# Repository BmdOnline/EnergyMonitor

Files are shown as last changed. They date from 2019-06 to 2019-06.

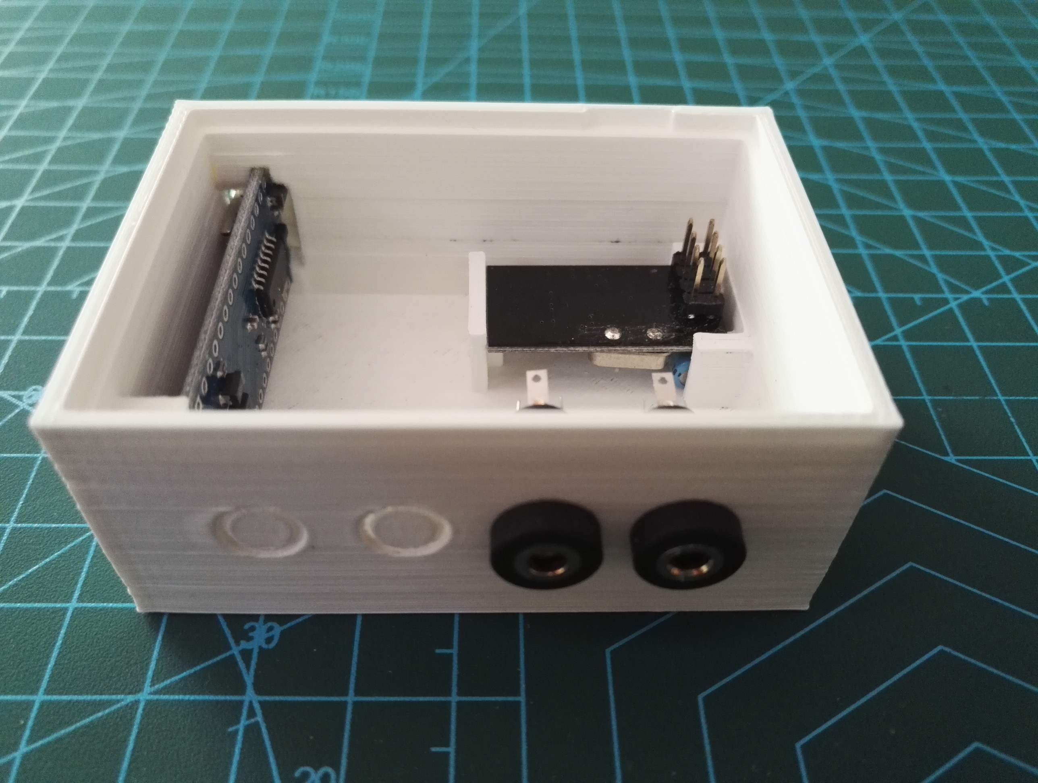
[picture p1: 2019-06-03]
hardware/pictures/IMG_20190603_105925_resize.jpg

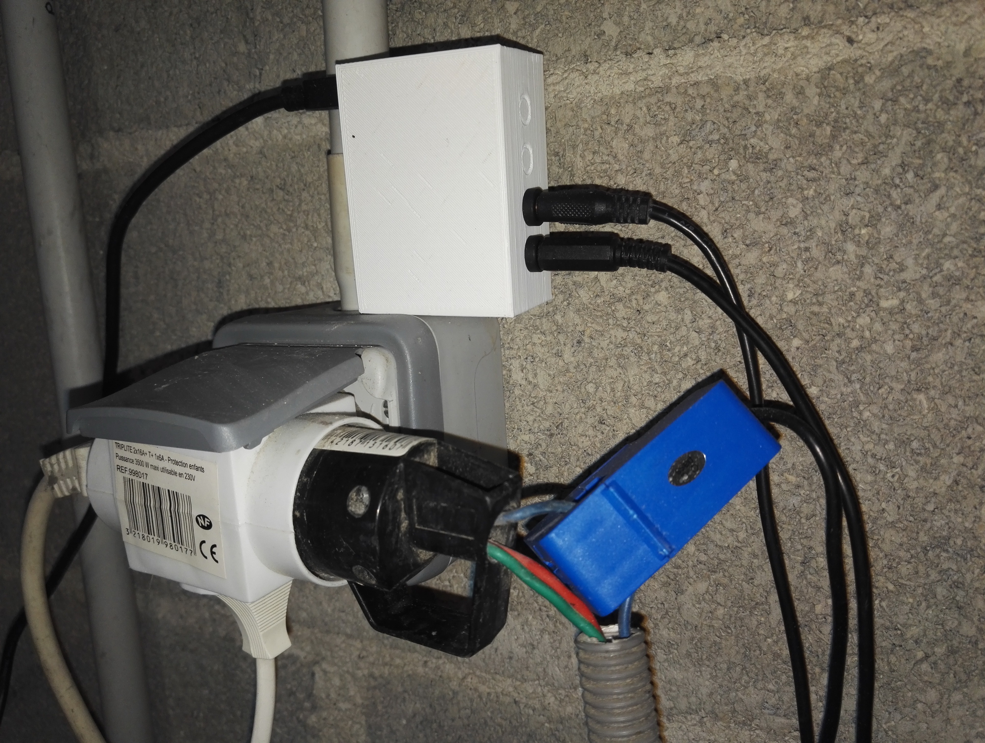
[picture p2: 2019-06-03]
hardware/pictures/IMG_20190603_145601_resize.jpg

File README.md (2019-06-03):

# EnergyMonitor
Arduino energy monitor, using SCT-013-030 current sensors

Project Links :
* [Software part, on GitHub](https://github.com/BmdOnline/EnergyMonitor)
* [Hardware part, on Thingiverse](https://www.thingiverse.com/thing:3670139)

This is a full energy monitor project :
* You can manage 1 to 6 sensors.
* You can configure it through USB (see below).
* It can communicate through USB, with any homemade software.
* It can communicate with any Home Automation System supporting MySensors (I'm using Domoticz).
* Full source is provided, you can customize it.

Needed parts :
* For each sensor :
  * 1x SCT-013-030 current sensor ([AliExpress](https://www.aliexpress.com/wholesale?SearchText=SCT+013+030)).
      * It also works with SCT-013-000 ([AliExpress](https://www.aliexpress.com/wholesale?SearchText=SCT+013+000)) (see below).
  * 1x 3.5mm Audio jack socket ([AliExpress](https://www.aliexpress.com/wholesale?SearchText=3.5mm+Audio+jack+socket)).
  * 2x 100k Resistor ([AliExpress](https://www.aliexpress.com/wholesale?SearchText=100k+Resistor)).
  * 1x 10µF Capacitor ([AliExpress](https://www.aliexpress.com/wholesale?SearchText=10uF+Capacitor)).
* 1x NRF24L01 wireless module ([AliExpress](https://www.aliexpress.com/wholesale?SearchText=NRF24L01)).
  * 1x 10µF Capacitor ([AliExpress](https://www.aliexpress.com/wholesale?SearchText=10uF+Capacitor)) (see below).
* 1x Arduino Nano ([AliExpress](https://www.aliexpress.com/wholesale?SearchText=Arduino+Nano)).

Instructions :
* Before to print case, you can specify how many sensors you have.
  * You can define the exact number of sensors, or plan more. Each socket will be pre-cut for future use.
* Follow joined scheme for assembly.
  * Each sensor have to be connected to A0, A1 and so on...
* Upload sketch to the Arduino Nano.
* Connect it to any computer for configuration (see below).
* Let's play...

Configuration parameters :
  * Number of sensors,
  * Sensor calibration (Vrms, ICal, IOffset),
  * Sample frequency,
  * Transmission frequency,
  * Toggle MySensors on/off,
  * Toggle serial output on/off.

Configuration will be saved to eeprom.

Using serial console, you can communicate with the sensor.
For example, using minicom (? for show help) :
<pre><code>$ minicom -b 115200 -D /dev/ttyUSB0

 __  __       ____
|  \/  |_   _/ ___|  ___ _ __  ___  ___  _ __ ___
| |\/| | | | \___ \ / _ \ `_ \/ __|/ _ \| `__/ __|
| |  | | |_| |___| |  __/ | | \__ \  _  | |  \__ \
|_|  |_|\__, |____/ \___|_| |_|___/\___/|_|  |___/
        |___/                      2.3.1

Energy Sensor has powered up

Energy Sensor (can use up to 6 sensors)
F0:<val> : Sample frequency in seconds (F0:5)
F1:<val> : Send frequency in seconds (F0:60)
E#:[0|1] : Enable Sensor # (E0:1[;E1:1])
V<#:val> : Set Vrms (V0:230[;V1:230])
C<#:val> : Set ICal (I0:29.95[;I1:29.98])
O<#:val> : Set intensity offset (O0:0.05[;I1:0.07])
S[0|1]   : Toggle Serial output
T[0|1]   : Enable MySensors transmission
M<#>     : Sensor mode (1: power, 2: current, 3: power+current)
all commands are case insentitive

F0:2;F1:60
E0:1:V0:230:C0:29.40:O0:0.01
E1:1:V1:230:C1:32.00:O1:0.05
S0;T1
M3
</code></pre>

Latest lines show current configuration.

Warning :
If you are using SCT-013-000 instead of SCT-013-030, you have to add burden resistor.
NRF24L01 may have connection issues. You have to add 10µF capacitor between PWR and GND.

You'll be handling dangerous voltages.
I decline any responsibility in case of any incident or accident.

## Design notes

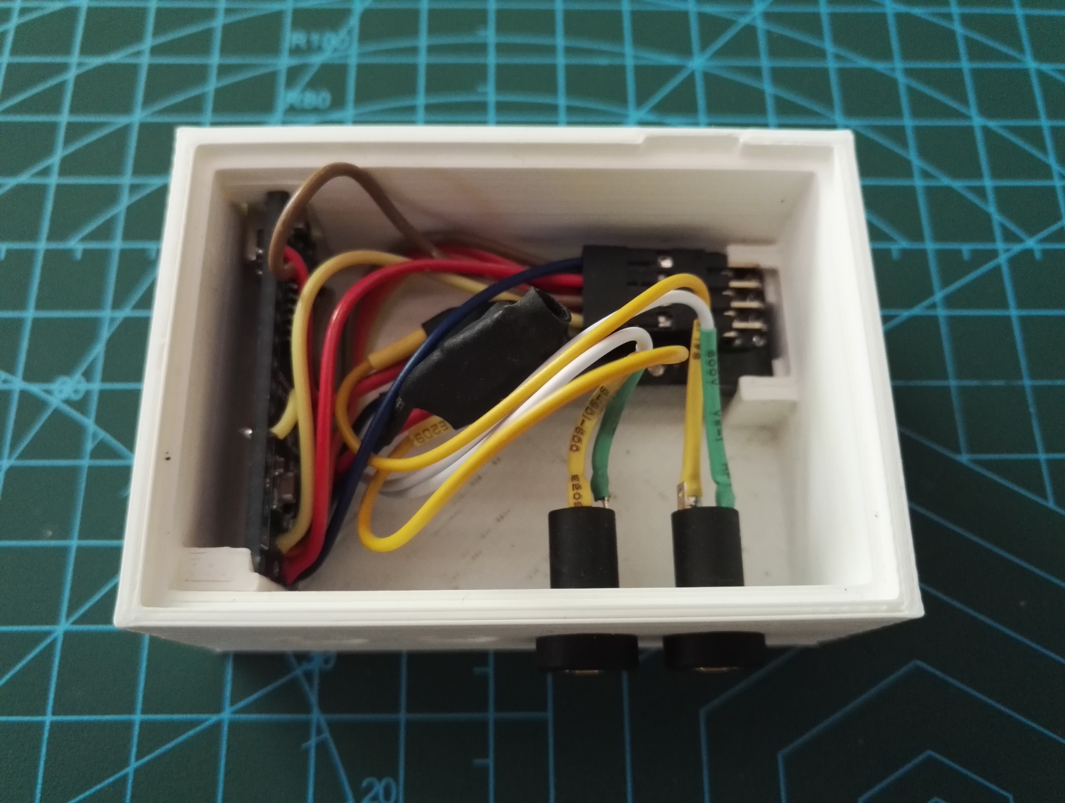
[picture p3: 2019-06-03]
hardware/pictures/IMG_20190603_130210_resize.jpg

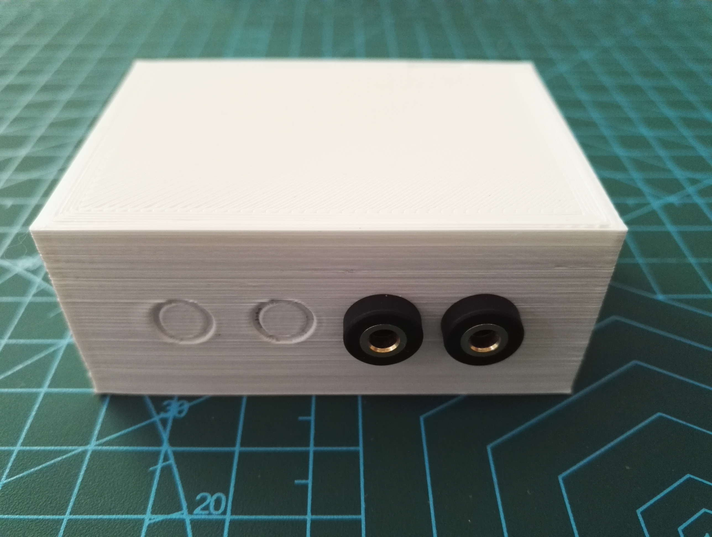
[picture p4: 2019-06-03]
hardware/pictures/IMG_20190603_130322_resize.jpg

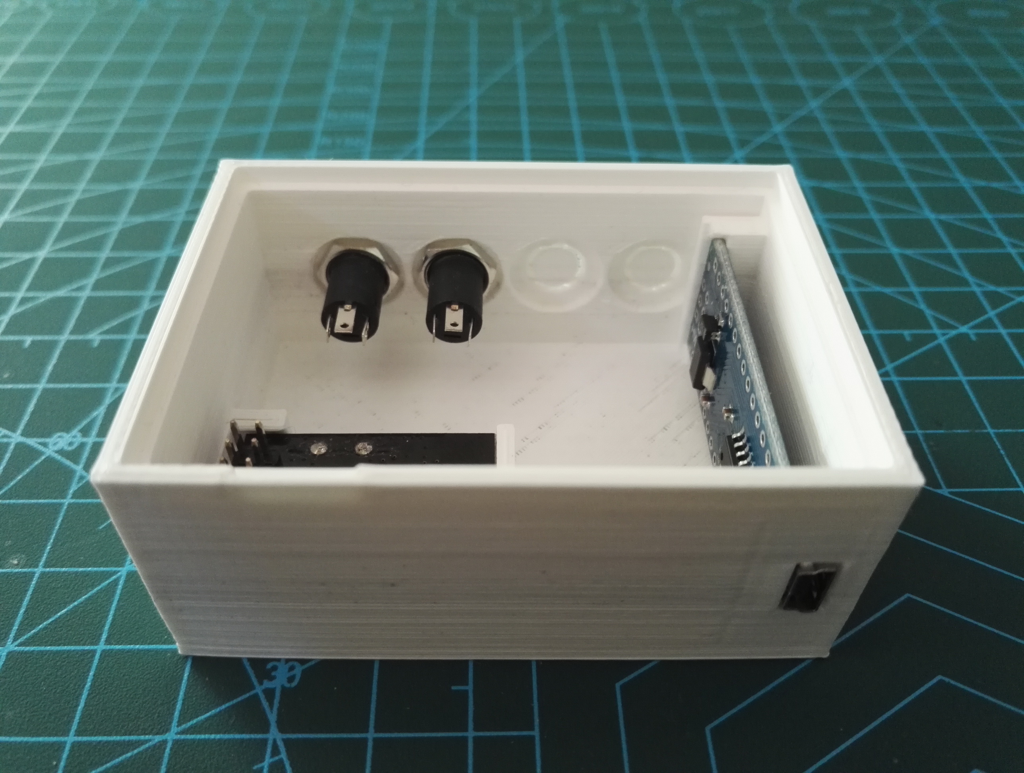
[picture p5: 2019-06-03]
hardware/pictures/IMG_20190603_105935_resize.jpg

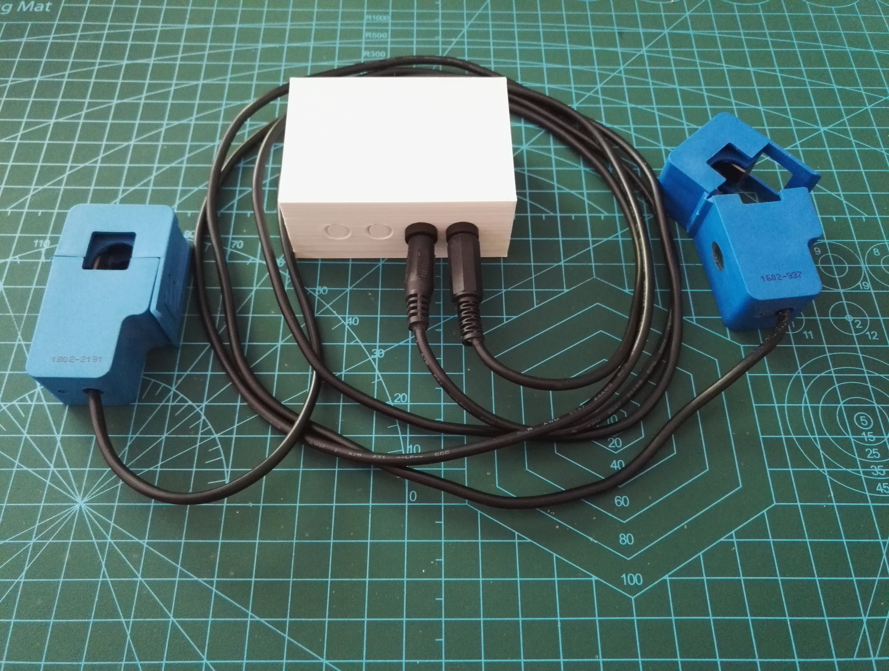
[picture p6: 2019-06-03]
hardware/pictures/IMG_20190603_130458_resize.jpg

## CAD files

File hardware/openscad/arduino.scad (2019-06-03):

$fn = 100;

include <modules.scad>

ArduinoNano_width = 17.78;
ArduinoNano_length = 43.18;
ArduinoNano_height = 7.25;
ArduinoNano_pcb_height = 2; //1.5;

ArduinoNano_usb_offset_y = 2.0; // 1.3;
ArduinoNano_usb_length = 10.0; // 9.25;
ArduinoNano_usb_width = 8.0; // 7.6;
ArduinoNano_usb_height = 4.0; // 3.75;

ArduinoNano_support_thickness = 2;
ArduinoNano_support_width = ArduinoNano_width+ArduinoNano_support_thickness*2;
ArduinoNano_support_length = ArduinoNano_length+ArduinoNano_support_thickness;
ArduinoNano_support_height = ArduinoNano_usb_height+0.5;

ArduinoNano_support_offset_x = ArduinoNano_support_thickness;
ArduinoNano_support_offset_y = 1.15;
ArduinoNano_support_offset_z = 4.5;

module ArduinoNano_board(upsideDown=true) {
    yangle = upsideDown?180:0;
    xoffset = upsideDown?ArduinoNano_width:0;
    zoffset = upsideDown?ArduinoNano_pcb_height:0;

    *translate([0, 0, 0]) cube([ArduinoNano_width, ArduinoNano_length, ArduinoNano_pcb_height]);
    rotate([0, yangle, 0]) translate ([40.1-xoffset, 87.1, ArduinoNano_pcb_height-zoffset]) rotate([0, 0, 180]) import("imports/2078_Nano.stl");
    *translate ([ArduinoNano_width/2+0.1, ArduinoNano_length/2-0.1, 0]) rotate([0, 0, 90]) import("imports/Nano.stl");
}

module trianglerect(width_a=10, width_b=10, height=2, center=false) {
    linear_extrude(height = height, center = center)
    polygon(points=[[0, 0], [0, width_a], [width_b, 0]]);
}

module ArduinoNano_support(height=ArduinoNano_usb_offset_y, support_offset_y=ArduinoNano_usb_offset_y, cover_end=false){
    *%translate([0, 0, 0]) cube([ArduinoNano_width, ArduinoNano_length, ArduinoNano_pcb_height]);
    difference() {
        union() {
            // rear
            // rear left stop
            *translate([-ArduinoNano_support_thickness, ArduinoNano_length-ArduinoNano_support_thickness, -ArduinoNano_support_height]) cube([ArduinoNano_support_thickness*2, ArduinoNano_support_thickness*2, ArduinoNano_support_height+ArduinoNano_pcb_height]);
            translate([-ArduinoNano_support_thickness, ArduinoNano_length+ArduinoNano_support_thickness, -ArduinoNano_support_height]) rotate([0, 0, -90]) trianglerect(width_a=ArduinoNano_support_thickness*2, width_b=ArduinoNano_support_thickness*2, height=ArduinoNano_support_height+ArduinoNano_pcb_height);
            **translate([ArduinoNano_support_thickness, ArduinoNano_length+ArduinoNano_support_thickness, -ArduinoNano_support_height]) rotate([0, 0, -90]) trianglerect(width_a=ArduinoNano_support_thickness*2, width_b=ArduinoNano_support_thickness*2, height=ArduinoNano_support_height);

            *translate([0, ArduinoNano_length+ArduinoNano_support_thickness-ArduinoNano_support_thickness*1.25, -ArduinoNano_support_height]) cube([ArduinoNano_support_thickness, ArduinoNano_support_thickness*1.25, ArduinoNano_support_height+ArduinoNano_pcb_height+ArduinoNano_support_thickness]);

            // rear right stop
            **translate([ArduinoNano_width-ArduinoNano_support_thickness, ArduinoNano_length-ArduinoNano_support_thickness, -ArduinoNano_support_height]) cube([ArduinoNano_support_thickness*2, ArduinoNano_support_thickness*2, ArduinoNano_support_height+ArduinoNano_pcb_height]);
            translate([ArduinoNano_width+ArduinoNano_support_thickness, ArduinoNano_length+ArduinoNano_support_thickness, -ArduinoNano_support_height]) rotate([0, 0, 180]) trianglerect(width_a=ArduinoNano_support_thickness*2, width_b=ArduinoNano_support_thickness*2, height=ArduinoNano_support_height+ArduinoNano_pcb_height);
            **translate([ArduinoNano_width-ArduinoNano_support_thickness, ArduinoNano_length+ArduinoNano_support_thickness, -ArduinoNano_support_height]) rotate([0, 0, 180]) trianglerect(width_a=ArduinoNano_support_thickness*2, width_b=ArduinoNano_support_thickness*2, height=ArduinoNano_support_height);

            *translate([(ArduinoNano_width-ArduinoNano_support_thickness), ArduinoNano_length+ArduinoNano_support_thickness-ArduinoNano_support_thickness*1.25, -ArduinoNano_support_height]) cube([ArduinoNano_support_thickness, ArduinoNano_support_thickness*1.25, ArduinoNano_support_height+ArduinoNano_pcb_height+ArduinoNano_support_thickness]);

            // rear middle stop
            /*
            *translate([(ArduinoNano_width-ArduinoNano_support_thickness)/2, ArduinoNano_length-ArduinoNano_support_thickness, -ArduinoNano_support_height]) cube([ArduinoNano_support_thickness, ArduinoNano_support_thickness*2, ArduinoNano_support_height+ArduinoNano_pcb_height+ArduinoNano_support_thickness]);
            translate([(ArduinoNano_width-ArduinoNano_support_thickness)/2, ArduinoNano_length-ArduinoNano_support_thickness, -ArduinoNano_support_height]) cube([ArduinoNano_support_thickness, ArduinoNano_support_thickness*2, ArduinoNano_support_height+ArduinoNano_pcb_height*0]);
            *translate([(ArduinoNano_width-ArduinoNano_support_thickness)/2, ArduinoNano_length+ArduinoNano_support_thickness-ArduinoNano_support_thickness*1.25, -ArduinoNano_support_height]) cube([ArduinoNano_support_thickness, ArduinoNano_support_thickness*1.25, ArduinoNano_support_height+ArduinoNano_pcb_height+ArduinoNano_support_thickness]);
            */
            RearSize=0.85;
            translate([-ArduinoNano_support_thickness, ArduinoNano_length-ArduinoNano_support_thickness, -ArduinoNano_support_height]) cube([ArduinoNano_support_width, ArduinoNano_support_thickness*1, ArduinoNano_support_height+ArduinoNano_pcb_height*0]);
            translate([-ArduinoNano_support_thickness, ArduinoNano_length+ArduinoNano_support_thickness-ArduinoNano_support_thickness*RearSize, -ArduinoNano_support_height]) cube([ArduinoNano_support_width, ArduinoNano_support_thickness*RearSize, ArduinoNano_support_height+ArduinoNano_pcb_height+ArduinoNano_support_thickness/2]);

            // front
            // front left stop
            translate([-ArduinoNano_support_thickness, 0.5, -ArduinoNano_support_height]) cube([ArduinoNano_support_thickness*2, ArduinoNano_support_thickness, ArduinoNano_support_height+ArduinoNano_support_thickness+ArduinoNano_pcb_height]);
            translate([ArduinoNano_support_thickness, 0.5, -ArduinoNano_support_height]) trianglerect(width_a=ArduinoNano_support_thickness, width_b=ArduinoNano_support_thickness*1.25, height= ArduinoNano_support_height+ArduinoNano_support_thickness+ArduinoNano_pcb_height);
            // front right stop
            translate([ArduinoNano_width-ArduinoNano_support_thickness, 0.5, -ArduinoNano_support_height]) cube([ArduinoNano_support_thickness*2, ArduinoNano_support_thickness, ArduinoNano_support_height+ArduinoNano_support_thickness+ArduinoNano_pcb_height]);
            translate([ArduinoNano_width-ArduinoNano_support_thickness, 0.5, -ArduinoNano_support_height]) rotate([0, 0, 90]) trianglerect(width_a=ArduinoNano_support_thickness*1.25, width_b=ArduinoNano_support_thickness, height= ArduinoNano_support_height+ArduinoNano_support_thickness+ArduinoNano_pcb_height);
        }
        // notch
        translate([-0.2, -0.1, 0]) cube([ArduinoNano_width+0.4, ArduinoNano_length+0.4, ArduinoNano_pcb_height+0.1]);
    }

    // Arduino Nano cover end (usb)
    if (cover_end)
    translate([(ArduinoNano_width-ArduinoNano_usb_width)/2, -support_offset_y, -ArduinoNano_support_height-height]) cube([ArduinoNano_usb_width-0.2, support_offset_y, height]);

    // Arduino Nano cover end (support)
    //translate([0, -support_offset_y/2, -ArduinoNano_support_height-height]) cube([ArduinoNano_width, ArduinoNano_support_thickness+support_offset_y/2, height]);

}

module ArduinoNano_window(height=ArduinoNano_usb_height, offset_y=ArduinoNano_usb_offset_y, negative=false, upsideDown=false){
    yangle = upsideDown?180:0;
    xoffset = upsideDown?ArduinoNano_width:0;
    zoffset = upsideDown?ArduinoNano_pcb_height:0;
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

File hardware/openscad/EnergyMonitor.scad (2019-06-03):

//$fa = 0.01; $fs = 0.01;
$fn = 100;
//$vpr = [60, 0, 345];//cnc view point

include <modules.scad>;
include <arduino.scad>;
include <nrf24l01.scad>;
include <jack.scad>;

/* [Export] */
// Select part to generate (case,cover,all)
Part_to_export = 1; // [1:case,2:cover,0:all]

/* [Sensors] */
// Number of jack connectors
Number_of_sensors = 4;    // [1:6]

/* [Case Size] */
// Case Width (x)
Case_width = 70;
// Case Height (z)
Case_height = 30;
// Case Depth (y)
Case_depth = 50;

/* [Case Advanced] */
// Case Border thickness
Case_bt = 3.4;
// Case Front thickness
Case_ft = 3.4;
// Cover thickness
Case_ct = 2;
// Case Cover margin
Case_cm = 2;
// Cover Opening key
Case_opening = 10;     // Case opening key


// NRF24L01
//NRF24L01_offset_x = NRF24L01_support_length+(Case_width-NRF24L01_support_length)/2;
NRF24L01_offset_x = Case_bt*2;//Case_width-Case_bt*2;
//NRF24L01_offset_y = NRF24L01_support_width+(Case_depth-NRF24L01_support_width)/2;
NRF24L01_offset_y = Case_depth-NRF24L01_support_width;

// Arduino Nano
ArduinoNano_offset_x = Case_width; //-ArduinoNano_support_width-Case_bt;
ArduinoNano_offset_y = Case_depth;//ArduinoNano_support_width+Case_bt;

module Case_box() {
/*
Case_width        // Case Width (x)
Case_height       // Case Height (z)
Case_depth        // Case Depth (y)

Case_bt           // Case Border thickness
Case_ft           // Case Front thickness
Case_ct           // Case Cover thickness
Case_cm           // Case Cover margin

Case_opening      // Case opening key
*/
    // Front thickness adjustment
    Case_adj = Case_bt-Case_ft;
    // Cover margin according to front thickness

    Case_fm = min(Case_cm, Case_ft/2);
    difference() {
        // Box
        cube ([Case_width, Case_depth, Case_height]);
        // Borders
        translate ([Case_bt, Case_ft-0.1, -0.1]) cube ([Case_width-Case_bt*2, Case_depth+Case_adj-Case_bt*2, Case_height-Case_bt+0.2]);
        // Cover place - bottom
        translate ([Case_cm, Case_fm-0.1, -0.1]) cube ([Case_width-Case_cm*2, Case_depth-Case_cm-Case_fm+0.1, Case_ct+0.2]);
        // Opening key
        translate ([(Case_width-Case_opening)/5-0.1, Case_depth-Case_cm-0.1, -0.1]) cube ([Case_opening+0.1, Case_cm/2+0.1, Case_cm+0.2]);
    }
}

module Case_cover() {
/*
Case_width        // Case Width (x)
Case_depth        // Case Depth (y)

Case_ft           // Case Front thickness
Case_ct           // Case Cover thickness
Case_cm           // Case Cover margin
*/
    // Cover margin according to front thickness
    Case_fm = min(Case_cm, Case_ft/2);

    translate ([Case_cm, Case_fm-0.1, -0.1]) cube ([Case_width-Case_cm*2, Case_depth-Case_cm-Case_fm+0.2, Case_ct]);

}

module Case_base() {
/*
Case_width        // Case Width (x)
Case_depth        // Case Depth (y)
*/
    difference() {
        // Chassis
        /*translate([0, Case_height, 0])*/
            Case_box();

        // Arduino Nano
    translate([ArduinoNano_offset_x-ArduinoNano_support_offset_z-Case_bt, ArduinoNano_offset_y-ArduinoNano_support_offset_y, -ArduinoNano_support_offset_x+Case_height-Case_bt+0.1]) rotate([0, 90, 180])
                ArduinoNano_window(height=0.5, offset_y=2, negative=true, upsideDown=true);

        // Jack
        Jack_margin = ((Case_width-Case_bt*2)-(Number_of_sensors*Jack_width))/Number_of_sensors*0.5;
        //Jack_offset = Case_bt+Jack_width/2+Jack_margin/2;
        Jack_offset = Jack_width/2+(Case_width - (Number_of_sensors*Jack_width)-((Number_of_sensors-1)*Jack_margin))/2;
        for ( i= [0:1:Number_of_sensors-1]) {
            translate ([Jack_offset+(Jack_width+Jack_margin)*i, -0.2, Case_height/2]) Jack(negative=true);
        }

        *translate ([Jack_offset-Jack_width/2, 2-0.2, Case_height/2-Jack_width/2]) cube([Case_width-Jack_offset*2+Jack_width, Jack_filet_length, Jack_width]);
    }

    // NRF24L01
    translate([NRF24L01_offset_x-NRF24L01_support_offset_y, NRF24L01_offset_y-NRF24L01_support_offset_x, -NRF24L01_support_offset_z+Case_height-Case_bt+0.1]) rotate([0, 180, 270]) NRF24L01_support();

    // Arduino Nano
    translate([ArduinoNano_offset_x-ArduinoNano_support_offset_z-Case_bt, ArduinoNano_offset_y-ArduinoNano_support_offset_y, -ArduinoNano_support_offset_x+Case_height-Case_bt+0.1]) rotate([0, 90, 180])
    {
        ArduinoNano_support();
        *ArduinoNano_board(upsideDown=true);
    }
}

module Case_base_cover() {
    Case_cover();
}

module Case_base_components() {
    // NRF24L01
    translate([NRF24L01_offset_x-NRF24L01_support_offset_y, NRF24L01_offset_y-NRF24L01_support_offset_x, -NRF24L01_support_offset_z+Case_height-Case_bt+0.1]) rotate([0, 180, 270]) NRF24L01_board(version=1);


    // Arduino Nano
    translate([ArduinoNano_offset_x-ArduinoNano_support_offset_z-Case_bt, ArduinoNano_offset_y-ArduinoNano_support_offset_y, -ArduinoNano_support_offset_x+Case_height-Case_bt+0.1]) rotate([0, 90, 180])
        ArduinoNano_board(upsideDown=true);
    
    // Jack
    Jack_margin = ((Case_width-Case_bt*2)-(Number_of_sensors*Jack_width))/Number_of_sensors*0.5;
    //Jack_offset = Case_bt+Jack_width/2+Jack_margin/2;
    Jack_offset = Jack_width/2+(Case_width - (Number_of_sensors*Jack_width)-((Number_of_sensors-1)*Jack_margin))/2;
    for ( i= [0:1:Number_of_sensors-1]) {
        translate ([Jack_offset+(Jack_width+Jack_margin)*i, 0, Case_height/2]) Jack();
        translate ([Jack_offset+(Jack_width+Jack_margin)*i-Jack_width/2*0, 2, Case_height/2-Jack_width/2*0]) Jack_nut();
    }
}

/************************************************
 * Construct everything
 ************************************************/
 //Separate action for each child
module SeparateChildren(space) {
    for ( i= [0:1:$children-1])   // step needed in case $children < 2
      translate([i*space,0,0]) {
        children(i);
        //text(str(i));
      }
}

module main() {
    SeparateChildren(80){
        // Base
        //translate([0, 1.5*0, 0])
        Case_base();
        Case_base_cover();
        %Case_base_components(); // Components (for design only)
    }
}

module export(part=0){
    if (part==0) {
        main();
    } else if (part==1) {
        translate([Case_width, 0, Case_height]) rotate([0, 180, 0]) {
            Case_base();
            %Case_base_components(); // Components (for design only)
        }
    } else if (part==2) {
        translate([-Case_cm, -Case_cm, 0]) rotate([0, 0, 0])
        Case_base_cover();
    }
}

export(Part_to_export);

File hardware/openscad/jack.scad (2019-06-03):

$fn = 100;

include <modules.scad>

Jack_width = 10.25;
Jack_length = 20.7;

Jack_support_offset_x = Jack_width/2;
Jack_support_offset_y = 3.3; // Jack_face_length
Jack_support_offset_z = Jack_width/2;

/************************************************
 * Jack
 ************************************************/
Jack_face_diam = Jack_width;
Jack_face_length = 3.3;

Jack_ring_diam = 6.3;

Jack_filet_diam = 7.9;
Jack_filet_length = 4.3;
Jack_filet_min_len = 2.3; // Jack_nut_length or more (impact case depth)

Jack_tube_diam = 7.1;
Jack_tube_length = 12.6;

Jack_hole_diam = 3.5;
Jack_hole_length = 15.8;

Jack_pin_width = 2.1;
Jack_pin_height = 0.24;
Jack_pin_length1 = 3.1;
Jack_pin_length2 = 4.6;

Jack_nut_hex = 10;
Jack_nut_length = 2;

module Jack(negative=false) {
    if (negative) {
        // Outside hole
        color("DimGray") translate ([0, -0.1, 0]) rotate ([-90, 0, 0]) cylinder (h=0.5, r=Jack_filet_diam/2);
            
        // Outside pre cut
        difference() {
            color("DimGray") translate ([0, -0.1, 0]) rotate ([-90, 0, 0]) cylinder (h=0.9, r=Jack_filet_diam/2);
            color("DimGray") translate ([0, -0.2, 0]) rotate ([-90, 0, 0]) cylinder (h=0.9+0.2, r=(Jack_filet_diam/2)-0.8);
        }
            
        // Inside pre cut
        difference() {
            color("DimGray") translate ([0, -0.1+1.3, 0]) rotate ([-90, 0, 0]) cylinder (h=Jack_filet_length, r=Jack_filet_diam/2);
            color("DimGray") translate ([0, -0.2+1.3, 0]) rotate ([-90, 0, 0]) cylinder (h=Jack_filet_length+0.2, r=(Jack_filet_diam/2)-0.8);
        }

        // Inside hole
        color("DimGray") translate ([0, -0.1+1.7, 0]) rotate ([-90, 0, 0]) cylinder (h=Jack_filet_length, r=Jack_filet_diam/2);

        // Nut hole
        translate ([0, (Jack_filet_length-Jack_filet_min_len), 0]) rotate([-90, 0, 0]) cylinder(h=Jack_filet_length,r=Jack_nut_hex/2*1.2);
    }
    else {
    difference() {
        union() {
            color("DimGray") translate ([0, -Jack_face_length+0.1, 0]) rotate ([-90, 0, 0]) cylinder (h=Jack_face_length, r=Jack_face_diam/2);
            color("Goldenrod") translate ([0, -Jack_face_length, 0]) rotate ([-90, 0, 0]) cylinder (h=Jack_face_length, r=Jack_ring_diam/2);
            color("DimGray") translate ([0, -0.1, 0]) rotate ([-90, 0, 0]) cylinder (h=Jack_filet_length, r=Jack_filet_diam/2);
            color("DimGray") translate ([0, -0.1, 0]) rotate ([-90, 0, 0]) cylinder (h=Jack_tube_length, r=Jack_tube_diam/2);

            color("silver") translate ([-Jack_tube_diam/2*0.9, Jack_tube_length-0.2, -Jack_pin_width/2]) rotate ([0, 0, 0]) cube([Jack_pin_height, Jack_pin_length1, Jack_pin_width]);
            color("silver") translate ([Jack_tube_diam/2*0.9-Jack_pin_height, Jack_tube_length-0.2, -Jack_pin_width/2]) rotate ([0, 0, 0]) cube([Jack_pin_height, Jack_pin_length1, Jack_pin_width]);
            color("silver") translate ([-Jack_pin_width/2, Jack_tube_length-0.2, -Jack_tube_diam/2*0.9]) rotate ([0, 0, 0]) cube([Jack_pin_width, Jack_pin_length2, Jack_pin_height]);
        }

        // Jack connector hole
        translate ([0, -Jack_face_length-0.1, 0]) rotate ([-90, 0, 0]) cylinder (h=Jack_hole_length, r=Jack_hole_diam/2);
    }
    }
}

module Jack_nut() {
    color("silver") difference() {
        // Hex hole
        translate([0, Jack_nut_length, 0]) rotate([90, 0, 0]) cylinder(h=Jack_nut_length,r=Jack_nut_hex/2,$fn=6);
        // screw hole
        translate([0, Jack_nut_length+0.1, 0]) rotate([90, 0, 0]) cylinder(h=Jack_nut_length+0.2,r=Jack_filet_diam/2);
    }
}

*translate ([Jack_support_offset_x, Jack_support_offset_y, Jack_support_offset_z])
{
    difference() {
        translate ([-15, 0, -15]) cube([30, 4, 30]);
        Jack(negative=true);
    }
    *Jack_nut();
}

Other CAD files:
hardware/openscad/EnergyMonitor_merged.scad
hardware/openscad/modules.scad
hardware/openscad/nrf24l01.scad

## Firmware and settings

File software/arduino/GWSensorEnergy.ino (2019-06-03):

/**
 *
 * SensorEnergy
 *
 */

/* SCT013-030 - Current Sensor
   Connections
   ===========
    A0 and so on...
*/

/* nRF24L01 - 2.4GHz Transmitter
   Connections
   ===========
     VCC  to 3.3V DC
     GND  to GND
     CE   to digital pin 9
     CS   to digital pin 10
     MOSI to MOSI (digital pin 11)
     MISO to MISO (digital pin 12)
     SCK  to SCK  (digital pin 13)
     IRQ  to none
*/


    // Calibration, see SCT-013-030 datasheet
    //   built-in burden : 62 Ohms
    //   turn ratio      : 1800
    // Calibration = Ratio/BurdenR
    //   1800/62 = 29
    // See also :
    //   https://learn.openenergymonitor.org/electricity-monitoring/ctac/ct-and-ac-power-adaptor-installation-and-calibration-theory

//    sensors.current[0].Vrms = 230;
//    sensors.current[0].ICal = 29.40;
//    sensors.current[0].IZero = 0.01;

//    sensors.current[1].Vrms = 230;
//    sensors.current[1].ICal = 32.30;
//    sensors.current[1].IZero = 0.06;

// F0:5;F1:60
// E0:1;E1:1;E2:0;E3:0;E4:0;E5:0
// E0:1;V0:230;C0:29.40;O0:0.01
// E1:1;V1:230;C1:32:30;O1:0.05
// M3;S0;T0


/*--------------------------------------------------------------------------------------
  Main Defines
--------------------------------------------------------------------------------------*/
#define USE_MYSENSORS
#define USE_SERIAL
//#define USE_OLED
//#define USE_LCD
//#define DEBUG


#ifdef USE_MYSENSORS
// Enable and select radio type attached
#define MY_RADIO_NRF24
// wait until transport is ready
#define MY_TRANSPORT_WAIT_READY_MS 5000 // 5 seconds
// Enable debug prints to serial monitor
#define MY_DEBUG
//#define MY_RF24_CE_PIN 9   // Radio specific settings for RF24
//#define MY_RF24_CS_PIN 10  // Radio specific settings for RF24 (you'll find similar config for RFM69)
#endif

/*--------------------------------------------------------------------------------------
  Includes
--------------------------------------------------------------------------------------*/
#include "EmonLib.h"
#include <Wire.h>
#include <EEPROM.h>

#ifdef USE_MYSENSORS
// MySensors
#include <MySensors.h>
#endif

#ifdef USE_LCD
// https://bitbucket.org/fmalpartida/new-liquidcrystal/wiki/Home
#include <LiquidCrystal_I2C.h>
#endif

#ifdef USE_OLED
// https://github.com/olikraus/u8g2
#include <U8g2lib.h>
#endif

/*--------------------------------------------------------------------------------------
  Additional Defines
--------------------------------------------------------------------------------------*/
#define NB_SENSORS 6             // Number of sensors
#define SENSOR_PIN_n A0 // First sensor PIN, then increment

#ifdef USE_MYSENSORS
// MySensor
unsigned long SLEEP_TIME = 5000; // Sleep time between reads (in milliseconds)
#define CHILD_ID_POWER_n 0 // First child ID, then increment

// Wait times
#define LONG_WAIT 500
#define SHORT_WAIT 50
#endif


/*--------------------------------------------------------------------------------------
  Objects
--------------------------------------------------------------------------------------*/
#ifdef USE_MYSENSORS
// MySensor
//MySensor gw;
// Register all sensors to gw (they will be created as child devices)
// Look at MyMessage.h
//  S_MULTIMETER   //!< Multimeter device, V_VOLTAGE, V_CURRENT, V_IMPEDANCE
//    V_CURRENT    //!< S_MULTIMETER
//    V_VOLTAGE    //!< S_MULTIMETER
//    V_IMPEDANCE  //!< S_MULTIMETER, S_WEIGHT. Impedance value
//
//  S_POWER           //!< Power meter, V_WATT, V_KWH, V_VAR, V_VA, V_POWER_FACTOR
//    V_WATT          //!< S_POWER, S_BINARY, S_DIMMER, S_RGB_LIGHT, S_RGBW_LIGHT. Watt value for power meters
//    V_KWH           //!< S_POWER. Accumulated number of KWH for a power meter
//    V_VAR           //!< S_POWER, Reactive power: volt-ampere reactive (var)
//    V_VA            //!< S_POWER, Apparent power: volt-ampere (VA)
//    V_POWER_FACTOR  //!< S_POWER, Ratio of real power to apparent power: floating point value in the range [-1,..,1]
//
//  S_INFO            //!< LCD text device / Simple information device on controller, V_TEXT
//    V_TEXT          //!< S_INFO. Text message to display on LCD or controller device

MyMessage msg(0, 0);
/*MyMessage msgEnergy1(CHILD_ID_POWER_1, V_WATT);
MyMessage msgEnergy1(CHILD_ID_POWER_1, V_KWH);
MyMessage msgEnergy1(CHILD_ID_POWER_1, V_VAR1);*/
#endif

#ifdef USE_LCD
// Set the pins on the I2C chip used for LCD connections:
//                    addr, en,rw,rs,d4,d5,d6,d7,bl,blpol
LiquidCrystal_I2C lcd(0x27, 2, 1, 0, 4, 5, 6, 7, 3, POSITIVE);  // Set the LCD I2C address
#endif

#ifdef USE_OLED
U8G2_SSD1306_128X32_UNIVISION_F_HW_I2C u8g2(U8G2_R0);
#endif

// Include Emon Library
EnergyMonitor emon[NB_SENSORS];

/*--------------------------------------------------------------------------------------
  Variables
--------------------------------------------------------------------------------------*/

// Sensor
boolean metric = true;

// Instructions set, may use these separators
#define CMD_SEPARATOR ";" // Semicolon separates different instructions
#define ARG_SEPARATOR ":" // Coma separates different arguments from an instruction

#define NUM_CHARS 64      // May be 32, but decrease for memory consumption
#define END_CHAR '\0'

char receivedChars[NUM_CHARS] = {0}; // an array to store the received data
static byte ndx = 0;
boolean newData = false;

// ID of the settings block
#define CONFIG_VERSION "ct1"

// Tell it where to store your config data in EEPROM
#define CONFIG_START 32

struct config_t {
    // This is for mere detection if they are your settings
    char version[4];

    int sampleFrequency;
    int sendFrequency;
    byte sensorMode;

    byte enableTransmission;
    byte enableSerial;

    bool enabled[NB_SENSORS];
    int Vrms[NB_SENSORS];
    float ICal[NB_SENSORS];
    float IOffset[NB_SENSORS];
};

static config_t config = {
    .version = CONFIG_VERSION,

    .sampleFrequency = 5, // 5 sec betwen sample
    .sendFrequency = 60,  // 60 sec between send
    .sensorMode = 3,      // 1 : power, 2 : current, 3 : power+current

    .enableTransmission = false,
    .enableSerial = false,

    .enabled = {},
    .Vrms = {},
    .ICal = {},
    .IOffset = {}
};
bool configLoaded = false;

struct current_t {
    float Irms = 0;
    int power = 0;
    double wh = 0;
    boolean received = false;
};

struct sensors_t {
    // Vrms for apparent power readings (when no AC-AC voltage sample is present)
    current_t current[NB_SENSORS];
};

static sensors_t sensors;

const int no_of_samples = 1480;
int nb_samples = 0;

unsigned long lastSend = millis();
unsigned long lastSample = millis();
unsigned long currentMillis;

#ifdef USE_OLED
char StringFloat[6];
#endif

#if defined(USE_LCD) || defined(USE_OLED)
char StringOut[17]; //16 digits plus the null char
#endif

bool readSensors(unsigned long sampleDelay);

#ifdef USE_MYSENSORS
void sendMySensors (bool force);
#endif

/*--------------------------------------------------------------------------------------
  Main program
--------------------------------------------------------------------------------------*/
#ifdef USE_MYSENSORS
void presentSensor(int num) {
    String childName;
    char childChar[20];

    if ((config.enableTransmission) && (configLoaded)) {
        childName = "EnergyMonitor"+String(num+1);
        childName.toCharArray(childChar, 50);
        // 1 : power, 2 : current, 3 : power+current
        if ((config.sensorMode == 1) || (config.sensorMode == 3)) {
            #ifdef DEBUG
            Serial.print(F("DEBUG:Presenting POWER: ")); Serial.println(childName);
            #endif
            present(CHILD_ID_POWER_n+num, S_POWER, childChar);
        }
        if ((config.sensorMode == 2)) { // Only for current mode
            #ifdef DEBUG
            Serial.print(F("DEBUG:Presenting MULTIMETER: ")); Serial.println(childName);
            #endif
            present(CHILD_ID_POWER_n+num, S_MULTIMETER, childChar);
        }
        wait(SHORT_WAIT);
    }
}

void presentSensors() {
    if ((config.enableTransmission) && (configLoaded)) {
        // Register all sensors to gateway (they will be created as child devices)
        for (int i=0; i<NB_SENSORS; i++) {
            if (config.enabled[i]) {
                presentSensor(i);
            }
        }
    }
}

void presentation()
{
    // Load config from eeprom
    loadConfig();

    if (config.enableTransmission) {
        // Send the sketch version information to the gateway and Controller
        sendSketchInfo("Energy Sensor SCT013", "1.0");

        if (configLoaded) {
            presentSensors();
        }
    }
}

void receive(const MyMessage &message) {
    #ifdef DEBUG
    Serial.print(F("DEBUG:Message received: ")); Serial.print(message.sensor);
    Serial.print(F(", Type: ")); Serial.print(message.type);
    Serial.print(F(", Message: ")); Serial.print(message.getString());
    Serial.print(F(" (int)")); Serial.print(message.getInt());
    Serial.print(F(" (float)")); Serial.println(message.getFloat());
    #endif

    if (message.type==V_VAR1) {
        if ((message.sensor >=0) && (message.sensor < NB_SENSORS)) {
            sensors.current[message.sensor].wh = message.getFloat() * 1000 * 3600;
            sensors.current[message.sensor].received = true;
        } else {
            Serial.println(F(" unknown sensor received"));
        }
    } else {
        Serial.println(F(" unknown message received"));
    }
}

// This is called when a new time value was received
void receiveTime(unsigned long controllerTime) {
    Serial.print(F("Time value received: "));
    Serial.println(controllerTime);
    //#include <Time.h>                  //http://playground.arduino.cc/Code/Time
    //setTime(controllerTime);           // time from controller
    //timeReceived = true;
}
#endif

void loadConfig() {
    // To make sure there are settings, and they are YOURS!
    // If nothing is found it will use the default settings.
    /*if (EEPROM.read(CONFIG_START + 0) == CONFIG_VERSION[0] &&
        EEPROM.read(CONFIG_START + 1) == CONFIG_VERSION[1] &&
        EEPROM.read(CONFIG_START + 2) == CONFIG_VERSION[2])
    for (unsigned int t=0; t<sizeof(config); t++)
        *((char*)&config + t) = EEPROM.read(CONFIG_START + t);*/

    if (loadState(CONFIG_START + 0) == CONFIG_VERSION[0] &&
        loadState(CONFIG_START + 1) == CONFIG_VERSION[1] &&
        loadState(CONFIG_START + 2) == CONFIG_VERSION[2])
    for (unsigned int t=0; t<sizeof(config); t++)
        *((char*)&config + t) = loadState(CONFIG_START + t);

    configLoaded = true;
}

void saveConfig() {
    for (unsigned int t=0; t<sizeof(config); t++)
        //EEPROM.write(CONFIG_START + t, *((char*)&config + t));
        saveState(CONFIG_START + t, *((char*)&config + t));
}

/**
 * Initial configuration
 */
void setup()
{
    Serial.begin(115200);
    Serial.println(F("Energy Sensor has powered up"));

    #ifdef USE_MYSENSORS
    metric = getControllerConfig().isMetric;
    // true (=metric) Report sensor data in Celsius, meter, cm, gram, km/h, m/s etc..
    // false (=imperial) - Fahrenheit, feet, gallon, mph etc...
    // https://www.mysensors.org/download/sensor_api_20#controller-configuration

    // get the time from controller (handled by receiveTime)
    //requestTime(receiveTime);
    #endif

    // Set default values
    for (int i=0; i<NB_SENSORS; i++) {
        if (i==0) {
            config.enabled[i] = true;
        } else {
            config.enabled[i] = false;
        }
        config.Vrms[i] = 230;
        config.ICal[i] = 30;
        config.IOffset[i] = 0;
    }
    // Then try to load config from eeprom
    loadConfig();

    // Initialize sensors data
    for (int i=0; i<NB_SENSORS; i++) {
        sensors.current[i].Irms = 0;
        sensors.current[i].power = 0;
        sensors.current[i].wh = 0;
        sensors.current[i].received = false;

        if (config.enabled[i]) {
            #ifdef USE_MYSENSORS
            if (config.enableTransmission) {
                // present sensors again (now config is loaded)
                //presentSensor(i);

                // request value from controller
                request(CHILD_ID_POWER_n+i, V_VAR1);
            }
            #endif

            emon[i].current(SENSOR_PIN_n+i, config.ICal[i]); // Current: input pin, calibration.

            // initial boot to charge up capacitor (no reading is taken) - testing
            emon[i].calcIrms(no_of_samples);
        }
    }

    //double Irms;
    #ifdef USE_LCD
        lcd.begin(16, 2);
        for(int i = 0; i< 3; i++) {
            lcd.backlight();
            delay(250);
            lcd.noBacklight();
            delay(250);
        }
        lcd.backlight(); // finish with backlight on  lcd.setBacklight(HIGH); // NOTE: You can turn the backlight off by setting it to LOW instead of HIGH
        lcd.clear();

        lcd.setCursor(0,0);
        lcd.print("1:");
        lcd.setCursor(0,1);
        lcd.print("2:");
    #endif

    #ifdef USE_OLED
        // U8G
        // Font list :https://github.com/olikraus/u8g2/wiki/fntlistall
        // Try also u8g2_font_prospero_bold_nbp_tf
        u8g2.begin();
        u8g2.clearBuffer();
        //u8g2.setFont(u8g2_font_smart_patrol_nbp_tf); // 9px height
        u8g2.setFont(u8g2_font_open_iconic_embedded_2x_t); // 8px height
        u8g2.setCursor(0,15);
        u8g2.print("C");
        u8g2.setCursor(0,31);
        u8g2.print("F");
        u8g2.sendBuffer();
        //u8g2.setFont(u8g2_font_cursor_tf);
        //u8g2.setCursor(8,10);
    #endif

    showHelp();
}

void loop()
{
    // millis rolls over naturally every 49+ days, micros every 71+ minutes
    currentMillis = millis();

    // Read instructions from the Serial Monitor
    readSerial(Serial);
    // Send instruction
    if (newData) {
        parseData(receivedChars);
    }

    if (currentMillis - lastSample > (unsigned long)(config.sampleFrequency)*1000) {
        #ifdef DEBUG
        Serial.println(F("DEBUG:Time to read from Sensor"));
        #endif

        if (readSensors(currentMillis - lastSample)) {
            if (currentMillis - lastSend > (unsigned long)(config.sendFrequency)*1000) {
                #ifdef DEBUG
                Serial.println(F("DEBUG:Time to send to MySensor"));
                #endif
                #ifdef USE_MYSENSORS
                sendMySensors(false);
                #endif

                nb_samples = 0;
                lastSend = currentMillis;
            }

            #ifdef USE_OLED
            // Refresh OLED
            showOLED();
            #endif

            #ifdef USE_LCD
            // Refresh LCD
            showLCD();
            #endif

            #ifdef USE_SERIAL
            showSerial();
            #endif
        };

        lastSample = currentMillis;
    }
}

// Check if data received, and read it
void readSerial(Stream &refSer) {
    char rc = END_CHAR;

    while ((refSer.available()) && (!newData)) {
        rc = refSer.read();
        switch (rc) {
            case '\r':
                // Discard it
                break;
            case '\n':
                receivedChars[ndx] = END_CHAR; // terminate the string
                if (ndx>0) newData = true;
                ndx = 0;
                #ifdef DEBUG
                refSer.print(F("received command "));
                refSer.println(receivedChars);
                #endif
                break;
            default:
                receivedChars[ndx] = rc;
                if (ndx < NUM_CHARS-1) {
                    ndx++;
                }
                break;
        }
    }
}

void showHelp() {
    Serial.print(F("Energy Sensor (can use up to ")); Serial.print(NB_SENSORS); Serial.println(F(" sensors)"));
    Serial.println(F("F0:<val> : Sample frequency in seconds (F0:5)"));
    Serial.println(F("F1:<val> : Send frequency in seconds (F0:60)"));
    Serial.println(F("E#:[0|1] : Enable Sensor # (E0:1[;E1:1])"));
    Serial.println(F("V<#:val> : Set Vrms (V0:230[;V1:230])"));
    Serial.println(F("C<#:val> : Set ICal (I0:29.95[;I1:29.98])"));
    Serial.println(F("O<#:val> : Set intensity offset (O0:0.05[;I1:0.07])"));
    Serial.println(F("S[0|1]   : Toggle Serial output"));
    #ifdef USE_MYSENSORS
    Serial.println(F("T[0|1]   : Enable MySensors transmission"));
    #endif
    Serial.println(F("M<#>     : Sensor mode (1: power, 2: current, 3: power+current)"));
    Serial.println(F("all commands are case insentitive"));
    Serial.println();
    Serial.print(F("F0")); Serial.print(F(ARG_SEPARATOR)); Serial.print(config.sampleFrequency);
    Serial.print(F(CMD_SEPARATOR));
    Serial.print(F("F1")); Serial.print(F(ARG_SEPARATOR)); Serial.println(config.sendFrequency);
    for (int i=0; i<NB_SENSORS; i++) {
        if (config.enabled[i]) {
            Serial.print(F("E")); Serial.print(i); Serial.print(F(ARG_SEPARATOR)); Serial.print(config.enabled[i]); Serial.print(F(ARG_SEPARATOR));
            Serial.print(F("V")); Serial.print(i); Serial.print(F(ARG_SEPARATOR)); Serial.print(config.Vrms[i]); Serial.print(F(ARG_SEPARATOR));
            Serial.print(F("C")); Serial.print(i); Serial.print(F(ARG_SEPARATOR)); Serial.print(config.ICal[i]); Serial.print(F(ARG_SEPARATOR));
            Serial.print(F("O")); Serial.print(i); Serial.print(F(ARG_SEPARATOR)); Serial.println(config.IOffset[i]);
        }
    }
    Serial.print(F("S")); Serial.print(config.enableSerial);
    #ifdef USE_MYSENSORS
    Serial.print(F(CMD_SEPARATOR));
    Serial.print(F("T")); Serial.print(config.enableTransmission);
    #endif
    Serial.println();
    Serial.print(F("M")); Serial.println(config.sensorMode);
}

void parseData(char* receivedData) {
    char *tok, *saved;
    if (strlen(receivedData) > 0) {
        for (tok = strtok_r(receivedData, CMD_SEPARATOR, &saved); tok; tok = strtok_r(NULL, CMD_SEPARATOR, &saved)) {
            parseCommand(tok);
        }
    } else {
        // Nothing to parse, may not happens
        newData = false;
    }
}
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
